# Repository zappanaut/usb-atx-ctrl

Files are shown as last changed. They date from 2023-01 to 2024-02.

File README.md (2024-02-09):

# usb-atx-ctrl
Using RP2040-Zero to control ATX operations via USB.

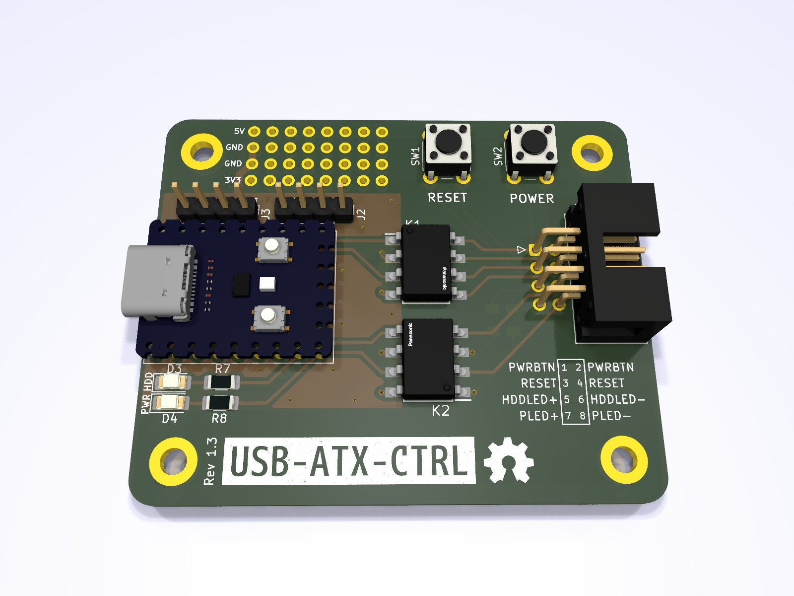
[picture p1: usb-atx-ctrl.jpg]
PCB rendering


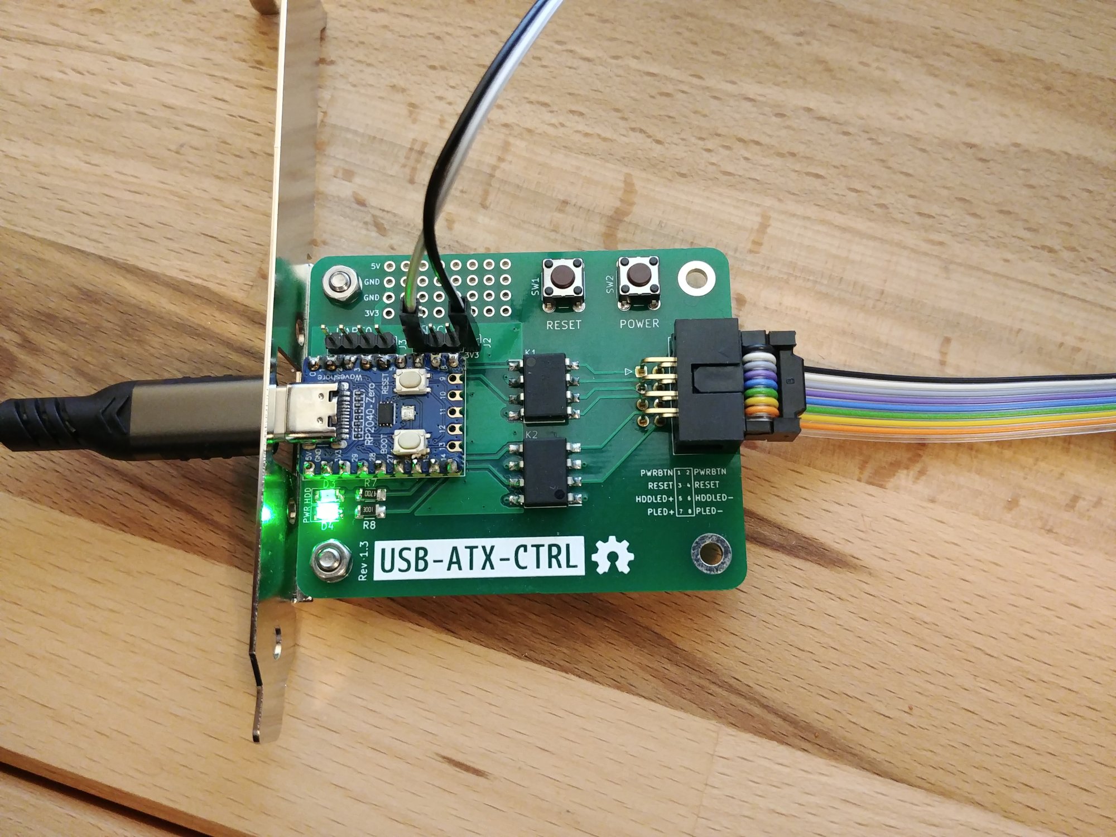
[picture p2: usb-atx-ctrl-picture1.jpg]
Pupulated PCB

*Populated board attached to old network card bracket (J2 is only connected for debugging!)*

A good fit is the Intel E23237-001 slot bracket.

### HOWTO

This repository is part of my [pikvm-usb-atx-ctrl](https://github.com/zappanaut/pikvm-usb-atx-ctrl) project. For more information please have a look at the aforementioned repository.

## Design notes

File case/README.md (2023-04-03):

This is a simple case for the PCB.

Use M3 threaded inserts for the lid. Above the LEDs is a 5mm hole meant for a light guide. I
simply used a piece of a 5mm acrylic rod.

Enjoy.

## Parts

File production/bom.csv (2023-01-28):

Designator | Footprint | Quantity | Value | LCSC Part #
D3 | 1206 | 1 | LED
D4 | 1206 | 1 | LED
J1 | IDC-Header_2x04_P2.54mm_Horizontal | 1 | ATX
J2 | PinHeader_1x04_P2.54mm_Vertical | 1 | I2C0
J3 | PinHeader_1x04_P2.54mm_Vertical | 1 | UART0
K1, K2 | SOP254P962X315-8N | 2 | AQW210EHA
R1 | 1206 | 1 | 560R
R2 | 1206 | 1 | 560R
R3 | 1206 | 1 | 560R
R4 | 1206 | 1 | 560R
R5 | 1206 | 1 | 33k
R6 | 1206 | 1 | 33k
R7 | 1206 | 1 | 560R
R8 | 1206 | 1 | 560R
RZ1 | RP2040-Zero | 1 | RP2040-Zero
SW1 | SW_PUSH_6mm | 1 | RESET
SW2 | SW_PUSH_6mm | 1 | POWER

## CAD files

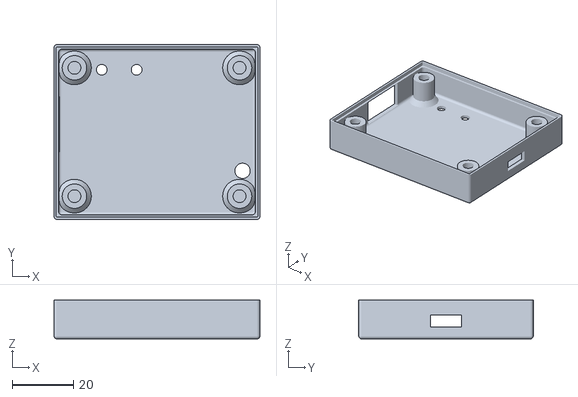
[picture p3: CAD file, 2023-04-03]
case/usb-atx-ctrl_lid.stl
67.3 x 57.1 x 12.7

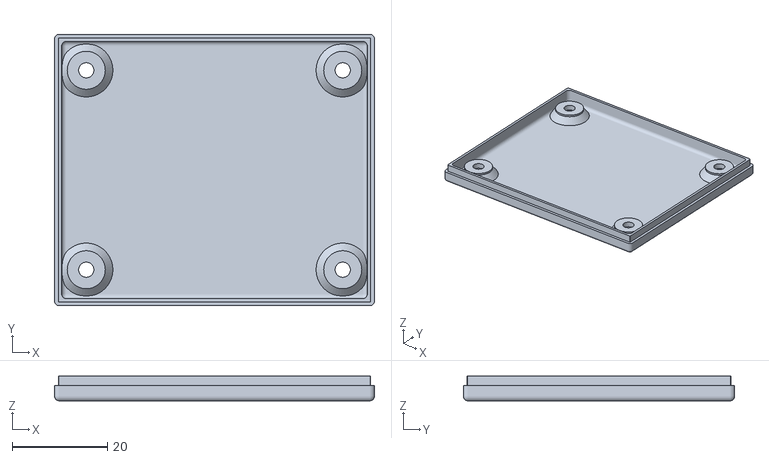
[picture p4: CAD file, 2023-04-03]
case/usb-atx-ctrl_base.stl
67.3 x 57.1 x 5.20

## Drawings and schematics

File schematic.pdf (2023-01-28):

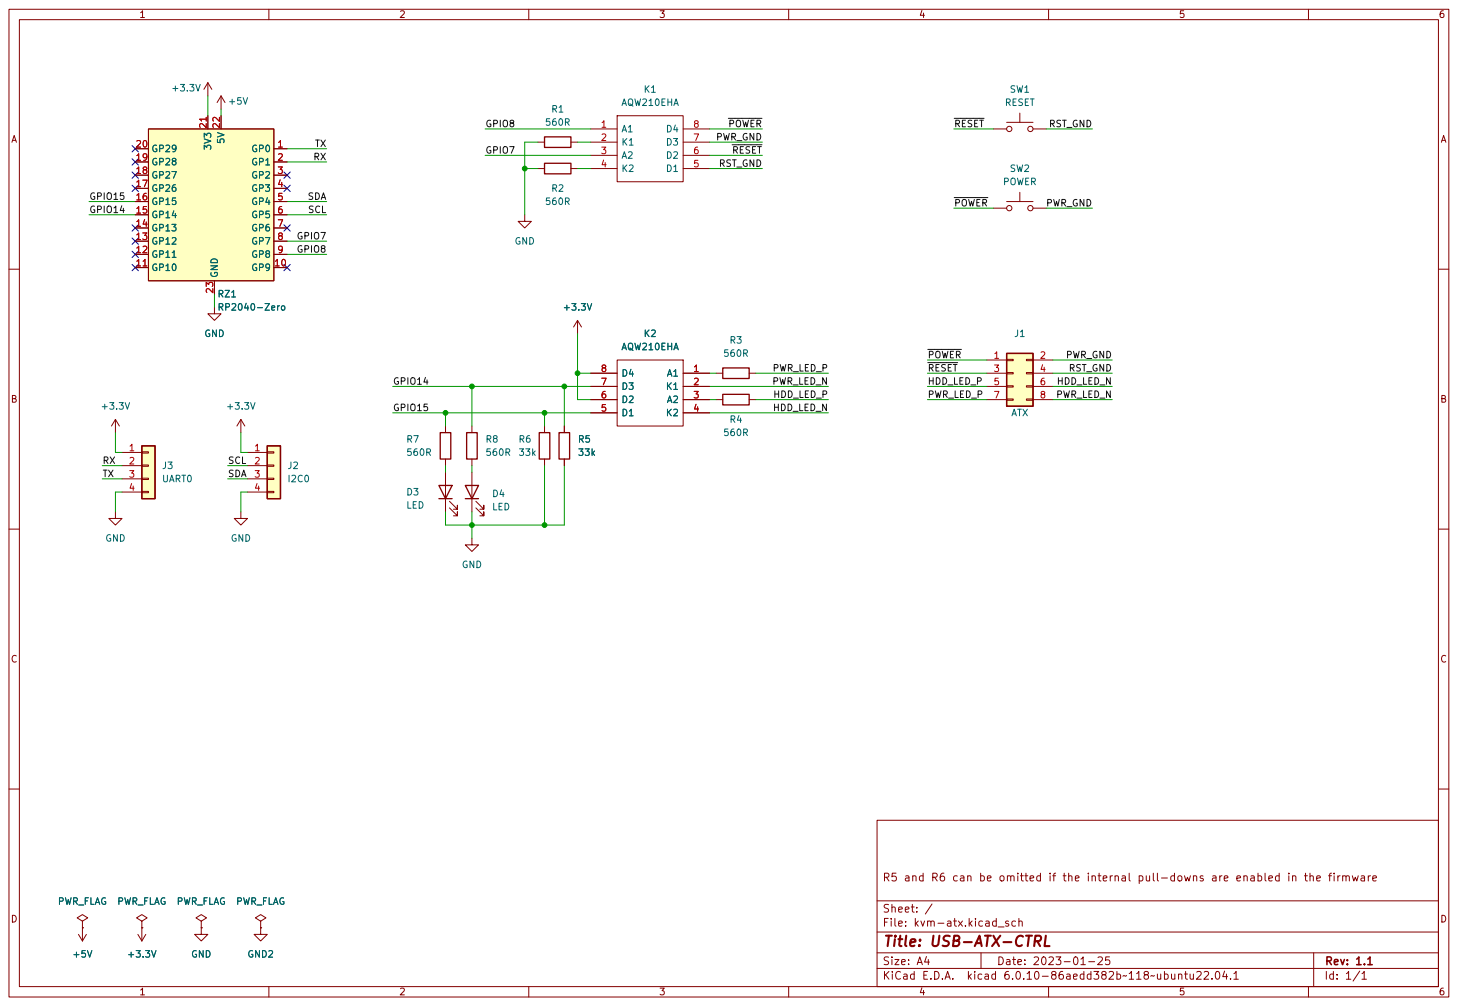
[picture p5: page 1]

File: kvm-atx.kicad_sch Sheet: / R5 and R6 can be omitted if the internal pull-downs are enabled in the firmware GND

Id: 1/1 Title: USB-ATX-CTRL

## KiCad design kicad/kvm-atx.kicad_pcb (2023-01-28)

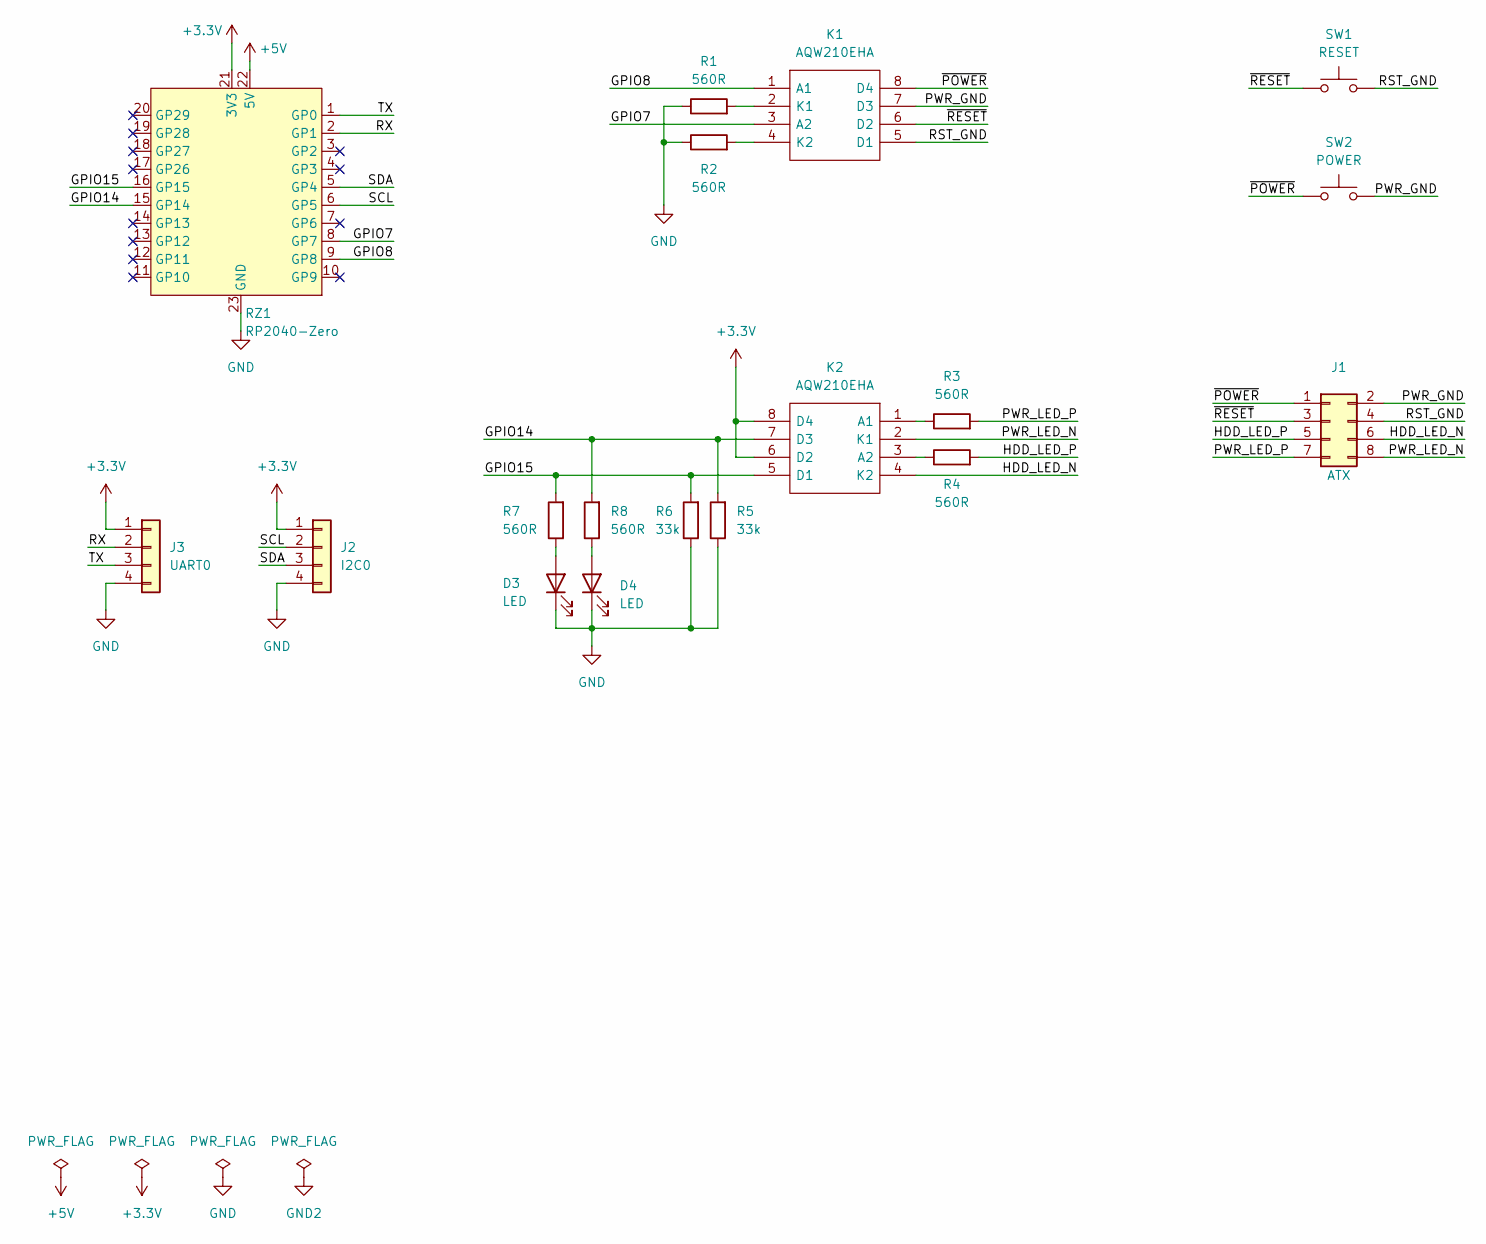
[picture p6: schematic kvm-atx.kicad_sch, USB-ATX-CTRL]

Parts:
D3, D4: LED; LED_1206_3216Metric_Pad1.42x1.75mm_HandSolder
J1: ATX; IDC-Header_2x04_P2.54mm_Horizontal
J2: I2C0; PinHeader_1x04_P2.54mm_Vertical
J3: UART0; PinHeader_1x04_P2.54mm_Vertical
K1, K2: AQW210EHA; SOP254P962X315-8N; Manufacturer_Part_Number AQW210EHA; Mouser Part Number 769-AQW210EHA
R1, R2, R3, R4, R7, R8: 560R; R_1206_3216Metric_Pad1.30x1.75mm_HandSolder
R5, R6: 33k; R_1206_3216Metric_Pad1.30x1.75mm_HandSolder
RZ1: RP2040-Zero
SW1: RESET; SW_PUSH_6mm
SW2: POWER; SW_PUSH_6mm

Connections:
+3.3V: J2.1, J3.1, K2.6 (D2), K2.8 (D4), RZ1.21 (3V3)
+5V: RZ1.22 (5V)
/GPIO7: K1.3 (A2), RZ1.8 (GP7)
/GPIO8: K1.1 (A1), RZ1.9 (GP8)
/GPIO14: K2.7 (D3), R5.2, R8.2, RZ1.15 (GP14)
/GPIO15: K2.5 (D1), R6.2, R7.2, RZ1.16 (GP15)
/HDD_LED_N: J1.6, K2.4 (K2)
/HDD_LED_P: J1.5, R4.2
/PWR_GND: J1.2, K1.7 (D3), SW2.2
/PWR_LED_N: J1.8, K2.2 (K1)
/PWR_LED_P: J1.7, R3.2
/RST_GND: J1.4, K1.5 (D1), SW1.2
/RX: J3.2, RZ1.2 (GP1)
/SCL: J2.2, RZ1.6 (GP5)
/SDA: J2.3, RZ1.5 (GP4)
/TX: J3.3, RZ1.1 (GP0)
/~POWER: J1.1, K1.8 (D4), SW2.1
/~RESET: J1.3, K1.6 (D2), SW1.1
GND: D3.1 (K), D4.1 (K), J2.4, J3.4, R1.1, R2.1, R5.1, R6.1, RZ1.23 (GND)
unnamed: D3.2 (A), R7.1
unnamed: D4.2 (A), R8.1
unnamed: K1.2 (K1), R1.2
unnamed: K1.4 (K2), R2.2
unnamed: K2.1 (A1), R3.1
unnamed: K2.3 (A2), R4.1

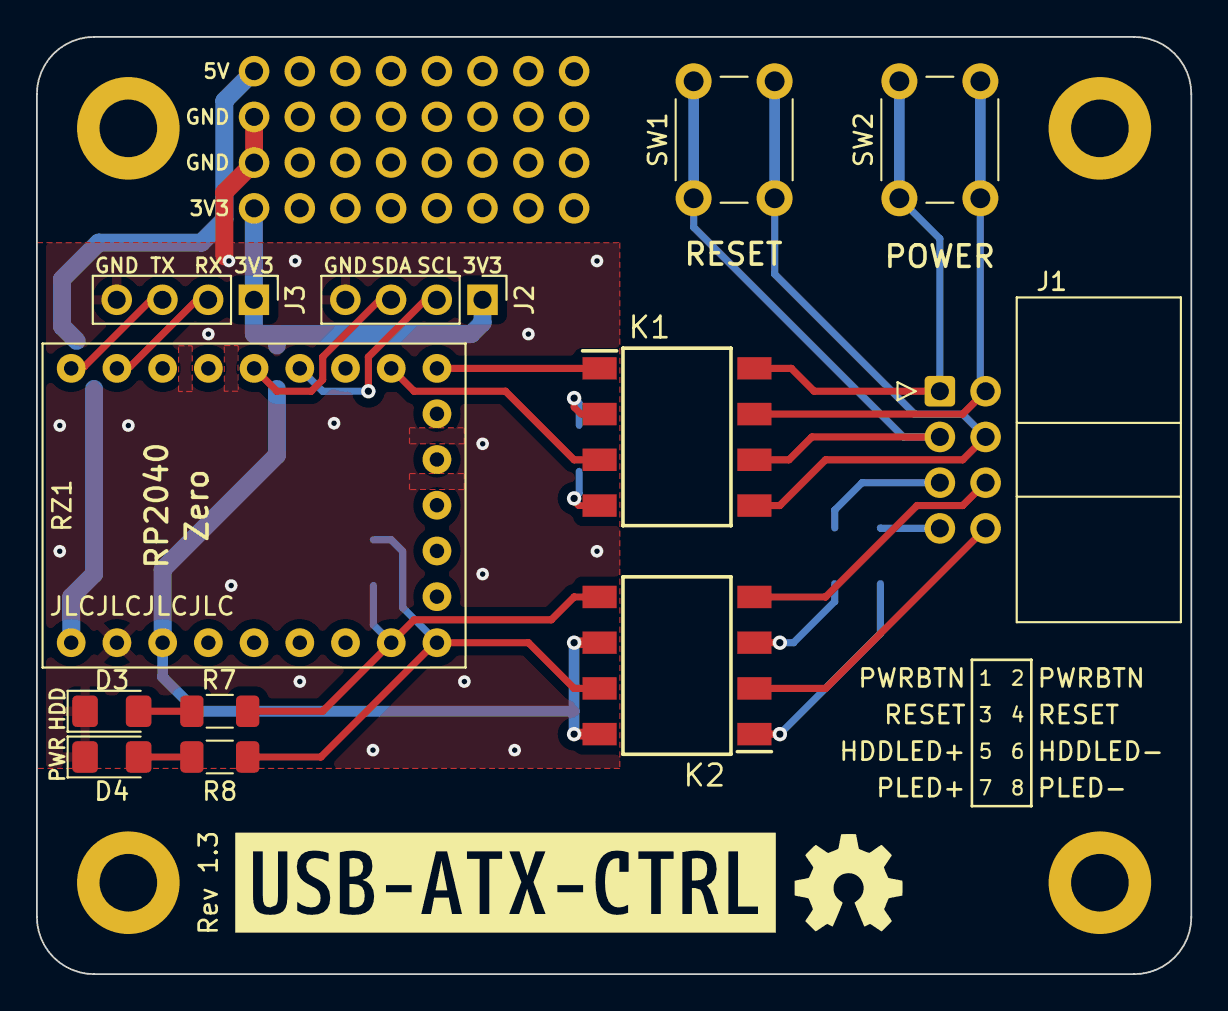
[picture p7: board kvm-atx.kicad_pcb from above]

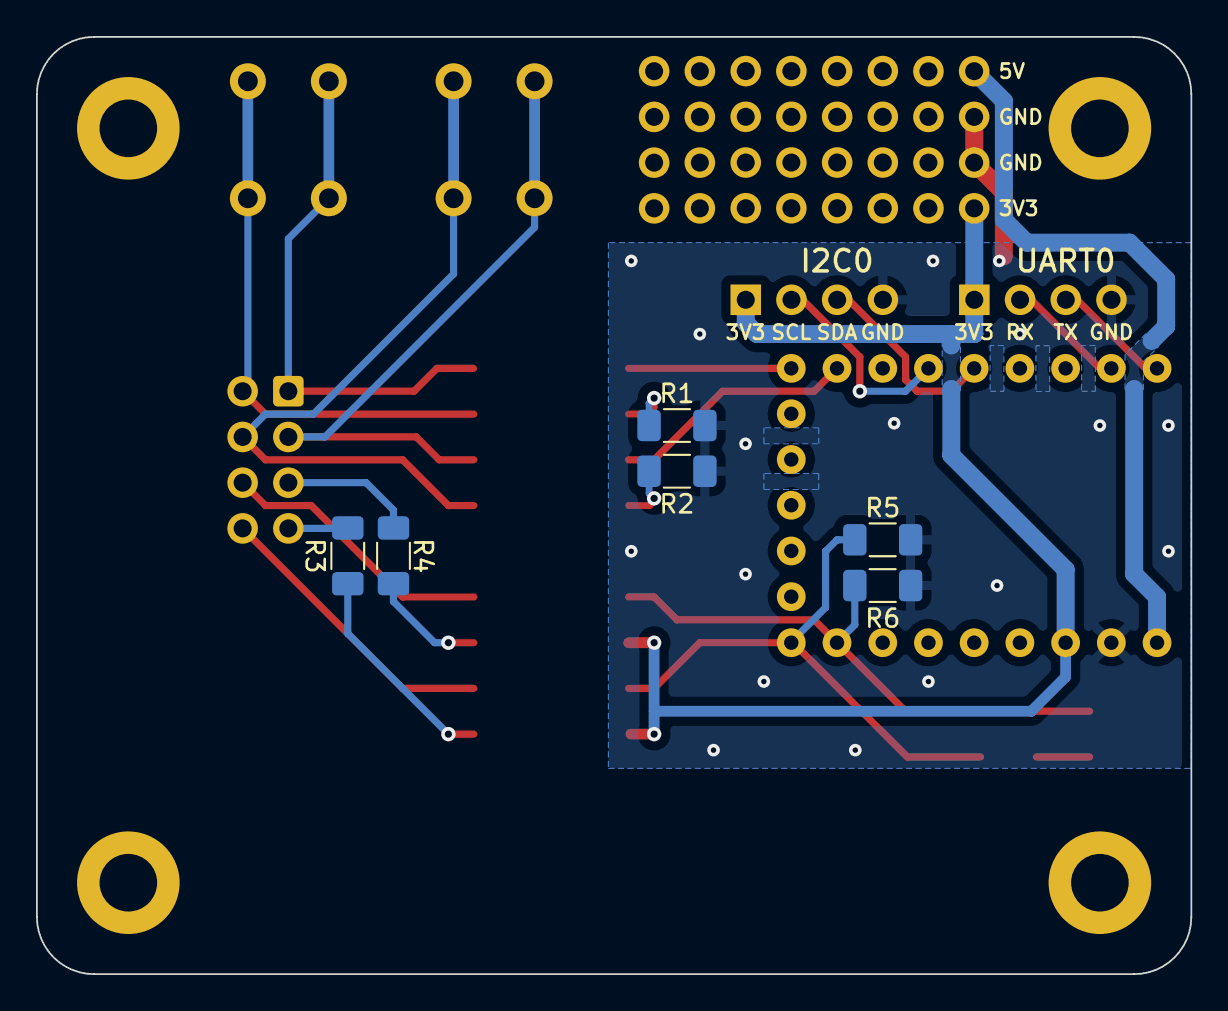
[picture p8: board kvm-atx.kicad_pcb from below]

Board: 2 copper layers, 64.1 x 52.1 mm, 20 parts (6 on the bottom side), 24 nets.

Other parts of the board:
G1: LOGO
kibuzzard-639AEF10: G***; kibuzzard-639AEF10

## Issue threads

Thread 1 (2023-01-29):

How to configure JLCPCB order

ProjectInitiative, 2023-01-29:
I am looking to place an order through JLCPCB. In https://github.com/pikvm/pikvm/issues/433 it was mentioned that costs were low. Is that only low if you solder everything yourself? I am not sure if I was inputting information correctly, but with assembly costs, it ended up being close to $70 USD.

Am I missing something?
Thanks
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

zappanaut, 2023-01-29:
Costs should be at around $10 (depending on your location and shipping costs) only for the PCBs without assembly and stencil. You can see in the charge details that the bare PCBs are just $2. Unfortunately I never used the assembly service, so I fear I am of little help regarding that.

ProjectInitiative, 2023-01-29:
Gotcha, I might try my hand at soldering my own components. Admittedly I am not much of an electrical engineer, how does one solder the RP2040 zero to the PCB? With a header?

zappanaut, 2023-01-29:
Yes, the RP2040-Zero is soldered down with pin headers.

SchoolGuy, 2023-02-11:
@ProjectInitiative Did you use the assembly service in the end? I am in a similar situation as you are. If yes can you do a small writeup on how to actually add components (Raspi, ICs, ...)?

ProjectInitiative, 2023-02-11:
@SchoolGuy I did not end up going through with the purchase. Assembly on a two sided board was too high (~$70 without the components). JLCPCB also didn't offer/have all of the needed components. When I tried to source some of the relays, it ended up being more expensive than to just some blicube ATX adapters and build a new controller off of a Pico. If you want to see what I did: https://github.com/ProjectInitiative/pikvm-atx

zappanaut, 2023-02-12:
Last time I checked they had suitable and inexpensive PhotoMOS relays in stock. If someone wants to give it a try, I am happy to assist with picking the right parts.
@SchoolGuy In any case you have to buy and solder the RP2040-Zero yourself.

SchoolGuy, 2023-02-12:
@zappanaut Well if I manage to solder that one on by myself, I guess that the other components are also possible to solder on by myself? I am sadly not able to wield flux correctly (last time I tried I messed up the board and components I wanted to solder on) and thus I was looking to get a "plug and play" solution. The magic of hardware is not my strength. Are there any options for such a board like yours? Assembling sth like the PiKVM I was able to do but luckily the header was pre-produced and thus it was only a little bit of plugging the correct things into the correct jacks.

zappanaut, 2023-02-12:
@SchoolGuy for sure you need a little bit of practice. You may also want to use lead solder, that is way easier to handle. I deliberately chose 1206 sized parts for hand soldering. Tweezers are still necessary , though.
There is nothing wrong with using lots of flux (if it is proper flux meant for electronics and not for gutters). Simply clean the boards with 2-Propanol afterwards.
On YT there are lots of tutorials regarding soldering and I would like advice you to practice a bit with SMD soldering. And maybe a local hackerspace is also an option for you.
Regarding JLCPCB's assembly service, I think you have to send the proper bunch of production files to keep the cost down. That also means you have to assign the right JLCPCB partnumbers in the schematic, check parts orientation etc...

SchoolGuy, 2023-02-12:
@zappanaut Thanks for the advice. I will try my best. I'll report once I have it up and running (might take a while).

Closed 2023-02-11.

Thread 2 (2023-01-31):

A few simple questions about building these

mortenboldt, 2023-01-31:
Hi
Thank you for making this available. I've ordered 5 boards from JLCPCB and it came to $10.99 including shipping to Denmark.  I'm a software guy and I've never attempted to build anything like this, so I have a fun challenge ahead of my trying to solder the parts and get everything working.

A couple of questions

1. Am I right in assuming that I can just hook up pretty much any number of these through a USB hub?

2. In this picture you've got a 3.3v and a ground hooked up to J2. Where are you pulling those from? 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

3. In the picture it looks like a bracket from a network card. Do you know which card it came from, since it looks like the holes line up?

4. Any recommendation for a cheap place to buy the parts from the BOM?

Thank you
Morten

zappanaut, 2023-01-31:
Hello Morten,
I am also only a hobbyist EE ;) Regarding soldering it is important that you use proper flux and solder. Especially if you want to go lead-free you need additional flux - sometimes quite a lot of it. I am sure there are plenty of tutorials on YT though. I also chose quite "big" SMT parts for hand soldering. Maybe next time I will try the assembly service for these parts, too.

Regarding your Questions:
> 1.  Am I right in assuming that I can just hook up pretty much any number of these through a USB hub?

I don't see any limitations, but have to admit that I am using only two right now. In fact it was the main reason for me to build this, to monitor and control all PCs simultaneously.

> 2. In this picture you've got a 3.3v and a ground hooked up to J2. Where are you pulling those from?

These are only for powering another test board. You can safely ignore them.

> 3. In the picture it looks like a bracket from a network card. Do you know which card it came from, since it looks like the holes line up?

It is from an old PCI Ethernet card Intel Pro/100 that was collecting dust here for decades. But it also needed some metal rework. I think the distance of the screw holes (ca. 42mm) are quite common, though.

> 4. Any recommendation for a cheap place to buy the parts from the BOM?

Since you are located in Denmark, I went with these [PhotoMOS SSR](https://www.ebay.de/itm/185375265495) from ebay. There are no special requirements regarding the other parts. You can find them even on amazon. The IDC type pin header headers might be a bit more difficult to source, but you can also go with the simple ones.
These are distributors that come to mind, that are a bit less expensive (in no particular order):
* [TME](https://www.tme.eu), did not order from there yet, but heard no complains
* [Reichelt](https://www.reichelt.de), no complaints from me so far

Hope that gives you a good starting point and that you will enjoy this challenge! :)

mortenboldt, 2023-01-31:
Hello Peter,

Thank you very much for the answers.
I'm going to order the parts today and hopefully I will be controlling 4 machines in the not too distant future.

I'll post a message in here once I have it running.

Kind regards,
Morten

zappanaut, 2023-02-02:
@mortenboldt if you are still looking for brackets you may want to have a look at this offer: https://www.ebay.de/itm/274598193347

mortenboldt, 2023-02-02:
> @mortenboldt if you are still looking for brackets you may want to have a look at this offer: https://www.ebay.de/itm/274598193347

Thanks you very much.
I am having a friend 3D print some brackets, so I hope that will work.
The PCBs are on their way in the mail and I've ordered the components from the BOM.

mutsumi63, 2023-02-20:
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

hiarcy, 2023-08-04:
@zappanaut Hello, I'll be piggybacking a bit on this since I have questions along the same lines. These are definitely going to be beginner-ish questions as EE feels like rocket science to me.

Am I correct in understanding that you use a single board per client (i.e. PC with ATX pins), which then gets connected to a USB slot on the client itself or does it have to go straight to the HDMI switch?

I've yet to deal with anything custom boards so I'll be looking into KiCAD and how to get my own boards next. If I were to get them made, would I pass the supplier the entire KiCAD folder?

In the BOM, I believe K1/2 are relays and I see on the schematics R1-R4 are attached to them (not sure if this is the correct terminology). Does this mean that between the relay and the ATX connector I need to solder a resistor on the back?

Hopefully these questions makes sense, if not I will definitely try my best to further explain.

zappanaut, 2023-08-28:
@hiarcy, very sorry for being late with my reply!

> Am I correct in understanding that you use a single board per client (i.e. PC with ATX pins), which then gets connected to a USB slot on the client itself or does it have to go straight to the HDMI switch?

Yes, one board per connected computer. The USB connection goes directly to the PiKVM, so that you can control and monitor each computer independently from the KVM/HDMI switch.

> I've yet to deal with anything custom boards so I'll be looking into KiCAD and how to get my own boards next. If I were to get them made, would I pass the supplier the ~entire KiCAD folder~ gerber zip?

Usually you upload the gerber.zip zu e.g. JLCPCB and check the preview then to see if everything looks fine. I ordered from JLCPCB without any problems.

> In the BOM, I believe K1/2 are relays and I see on the schematics R1-R4 are attached to them (not sure if this is the correct terminology). Does this mean that between the relay and the ATX connector I need to solder a resistor on the back? Assuming this since I don't see it on the pictures showing the top of the board. Edit: Found the bottom side of the board, I believe this is correct.

Yes, K1/2 are PhotoMOS solid state relays. The resistors are limiting the current through the IR-LEDs inside the solid state relay and are placed on the backside of the PCB, as you already figured out.

Hope I could still help a bit and feel free to ask if more questions arise.

hiarcy, 2023-08-29:
@zappanaut Perfect! Absolutely no worries, my parts should be coming in this week/early next week so I'll be able to mess around soon! I tend to learn better with on-hands experience. Will definitely reach out if I have any additional questions, thanks!

tiiilerteee, 2023-12-22:
@zappanaut  Hey, there! I know this hasn't had any activity for a few months, but I discovered the PiKVM a while back and was very excited to find something so great and less expensive than the commercial options; my only issue was controlling the power of multiple machines; and you have solved that! Very cool! Thank you. I am going to have 4 of your boards printed up from JLCPCB and try to get this project working. I currently only need KVM and ATX power control for two machines, but I would like to have a few extra boards in the event I want to expand later. Since it seems like you probably have been running this for a while, is there anything I should know before beginning? Any new pros or cons you have noticed since August? Thanks!

Two quick questions about where things plug in:

1. I think you answered @hiarcy 's question well but I wanted to clarify. Attached is a PDF of how I believe everything should be plugged in; can you confirm?

2. I see on usb-atx-ctrl-picture1.jpg that you have a black and white pair to +3.3v and GND (if I'm reading the schematic right). Is that to power the RPi Pico? If, so where does that power come from, or where does that black-and-white pair head to?
[PiKVM-Illustration.pdf](https://github.com/zappanaut/usb-atx-ctrl/files/13756811/PiKVM-Illustration.pdf)

 Thanks so much!

tiiilerteee, 2023-12-25:
FYI I wanted a back plate that fit a USB-C perfectly, after searching everywhere I finally found this: https://a.co/d/5WCrTXV

I'm going to buy a few and remove the board that comes with it and measure to make sure the ATX-CTRL will fit, if not I'll adjust the board mount points before I have them printed. I'll report back what I find.

zappanaut, 2024-02-06:
Hello @tiiilerteee! I am very sorry for the huge delay!

> @zappanaut Hey, there! I know this hasn't had any activity for a few months, but I discovered the PiKVM a while back and was very excited to find something so great and less expensive than the commercial options; my only issue was controlling the power of multiple machines; and you have solved that! Very cool! Thank you. I am going to have 4 of your boards printed up from JLCPCB and try to get this project working. I currently only need KVM and ATX power control for two machines, but I would like to have a few extra boards in the event I want to expand later. Since it seems like you probably have been running this for a while, is there anything I should know before beginning? Any new pros or cons you have noticed since August? Thanks!

I have two boards running for some time and did not notice any bigger problems. For me the most annoying is described here: https://github.com/pikvm/pikvm/issues/946
Another thing is, that you may have use smaller resistors to drive the relay diodes as described here: https://github.com/zappanaut/usb-atx-ctrl/issues/3

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

Your illustration shows exactly how the board should be connected! :)

>     2. I see on usb-atx-ctrl-picture1.jpg that you have a black and white pair to +3.3v and GND (if I'm reading the schematic right). Is that to power the RPi-2040Z? If, so where does that power come from, or where does that black-and-white pair head to?

Unfortunately this picture caused some confusion before. The black and white cable was attached only for debugging purpose, so there should be no need to connect these. The board is actually powered from the USB port.

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

Let me know if you have more questions. I will do my best to respond more quickly then.

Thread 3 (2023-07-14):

LED Model Number and Web UI Power/HDD LED's not working

Johannp02180, 2023-07-14:
Hello!

I was able to sucessfully build it but the LED's aren't working so I wanted to see which LED's you used in yours. Also I setup my override file very similar to yours but the icons for the power and HDD aren't working, do you know what I might be doing wrong? Are they related to the LED's not lighting up?

zappanaut, 2023-07-14:
Hi!

Sorry, that the LEDs are not working (yet). The "LEDs" in the web application are 1:1 "wired" to the LEDs on the board.
The type of the LED only has an influence on the brightness. But even if you don't put any they should work in the web application. There may be several reasons if it does not work at all:

1. The polarity of the LED connector from the mainboard is wrong.
2. The PhotoMOS relay is soldered the wrong way, or is broken (unlikely).
3. The impedance of the mainboard's LED voltage is to high to trigger the PhotoMOS relay.

(1.) and (2.) should be easy to fix or check. Next you can test if it works in principle by applying 3.3V or 5V from the RP2040 board to the LED inputs. If this works it is most probably a problem with the impedance and you have to lower the resistors R3 and R4. Around 330 Ohm should be a safe bet. Maybe you  measure the voltage across the power LED input on the board?

Regards
Peter

Johannp02180, 2023-07-16:
I'm not close to the server to test the components but I attached a photo of the PCB I soldered. I think something I could possible fix remotely is the web application? I attached a photo of what I see in the web application as well.

Thank you!

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

zappanaut, 2023-07-16:
The PCB looks good. I assume "power" and "reset" buttons are working, no? Did you flash the firmware from here: https://github.com/zappanaut/pico-usb-io-board?
For now my best guess is that it is a wiring (polarity) problem or the input resistor value for the PhotoMOS diodes is too high for your mainboard.
There is nothing to fix in the web application if the signal is not there. You can check the pin assignments in your override.yaml again, but I fear further debugging has to wait until you have access to the server again.

Johannp02180, 2023-07-17:
Yes, the power and reset buttons are working. The buttons in the web application also work. I used the same resistor values referenced in your BOM, but I'll double-check the values I used. Thank you!

zappanaut, 2023-07-17:
Ok, so it seems 560 Ohm for R3 and R4 is a bit too high for your mainboard. These values just worked for me and also kept the amount of resistor values in the BOM low.
If you don't have lower value resistors you can also go with 280 Ohm by simply soldering a second 560 Ohm resistor on top of the old one.

Johannp02180, 2023-07-17:
Ok, that makes sense I just assumed the LED's I used were the same without bothering to check the resistor values and LED voltages (oopsies). However, the web application should work otherwise. I'll have to double-check my connections and test if there is a signal on those pins. Thank you.

zappanaut, 2023-07-17:
Just to be a bit more clear ... the problem might be with the input resistors for the PhotoMOS (R3 and R4). The current limiting resistors for the LEDs does not effect the functionality but only the brightness.

Johannp02180, 2023-07-17:
Got it, I used 560ohm for R3 and R4.

Johannp02180, 2023-07-25:
I haven't had the chance to go back and test the components you mentioned but the power on/off does work, (really well!). If I wanted to keep the functionality of my existing power button, if I'm not mistaken are the existing button/front panel headers connections just parallel to the ones on your board?

zappanaut, 2023-08-01:
Yes, you can connect the front panel connectors in parallel to the board. I used ribbon cables to connect the PCB to the mainboard and simply crimped such an IDC connector to the cable: https://m.media-amazon.com/images/I/71Lu1ZdaqwL._AC_SL1500_.jpg

nvllsvm, 2024-03-15:
For those curious, I'm successfully using these LEDs on my builds:
- [Dialight 599-0480-127F (green)](https://www.mouser.com/ProductDetail/645-599-0480-127F)
- [Dialight 599-0411-127F (red)](https://www.mouser.com/ProductDetail/645-599-0411-127F)

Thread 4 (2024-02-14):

How can I order those PCB's?

tobiashochguertel, 2024-02-14:
I want some of the these PCBs, but you don't sell them, or?
Is it possible that you can provide instructions on how we can order the PCB from PCBWay https://www.pcbway.com/

PCBWay offers also to share the Project, so that others can easily order it. https://www.pcbway.com/project/

tobiashochguertel, 2024-02-14:
I can order the PCB also from JLCPCB, I think that doesn't make a big difference. It would be great when you share a screenshot(s) of the order configuration from JLCPCB so that I use the same values as you. I will then assemble it myself like you did it.

zappanaut, 2024-02-14:
Here is a screenshot (actually these are just the defaults):
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

tobiashochguertel, 2024-02-14:
There are also parts which have to be placed on the bottom, as I see in the `positions.csv` file, I'm right or?
Can you please provide me a picture of the bottom side?

I try to order the PCBs with as many parts already assembled as possible.

zappanaut, 2024-02-15:
Sure, here is a rendered image of the bottom side:
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
And a little disclaimer: I did not try the assembly service, but let me know how it went. :)

mrulke, 2024-08-06:
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

Know this hase been a while but where did you see the `positions.csv` file?

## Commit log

2023-01-28 Added KiCAD files
    [kvm-atx.kicad_pcb, kvm-atx.kicad_sch]
2023-01-28 Added production files (NOT verified but should work).
    [bom.csv]
2023-01-28 Added schematic and PCB rendering
2023-01-30 Added picture of the populated PCB
2023-04-03 Added a simple PCB case.
    [usb-atx-ctrl_base.stl, usb-atx-ctrl_lid.stl]
